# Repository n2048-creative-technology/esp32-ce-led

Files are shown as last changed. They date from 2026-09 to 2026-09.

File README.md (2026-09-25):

# ESP32-C6 LED Controller Board

A compact 2-layer PCB built around the **ESP32-C6-WROOM-1** module, providing
USB-C power/programming, on-board 3.3V regulation, ESD-protected USB
data lines, a reset button, and an addressable/status LED header. All
electronic parts are sourced against JLCPCB's live parts catalog for
turnkey assembly.

## 3D Renders

| Top side (regulator / passives) | Bottom side (ESP32 module / USB-C) |
|---|---|
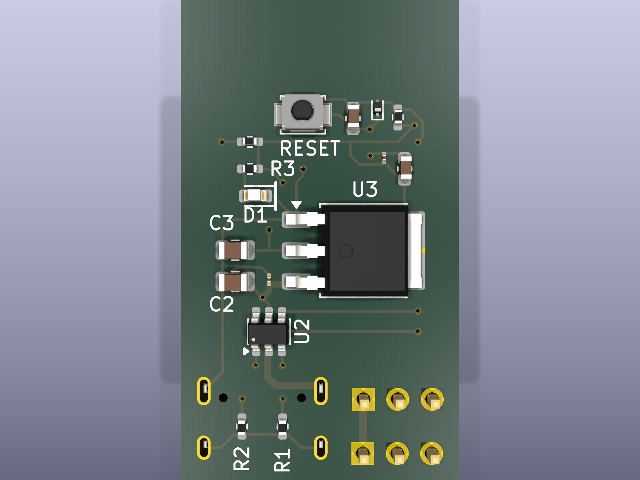
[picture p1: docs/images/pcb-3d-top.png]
PCB top 3D render
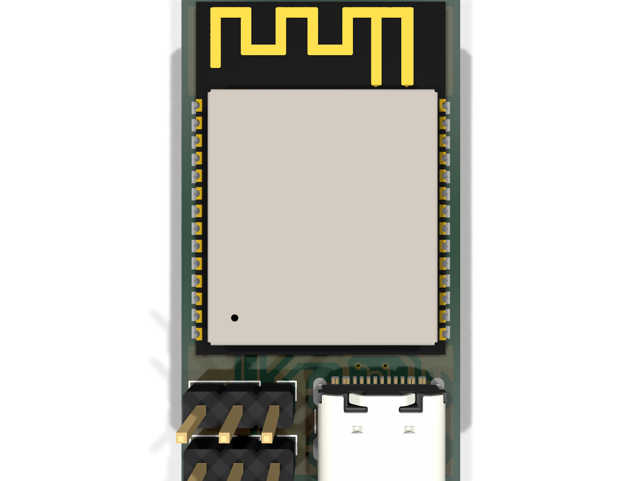
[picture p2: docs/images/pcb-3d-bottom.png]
PCB bottom 3D render
|  |  |

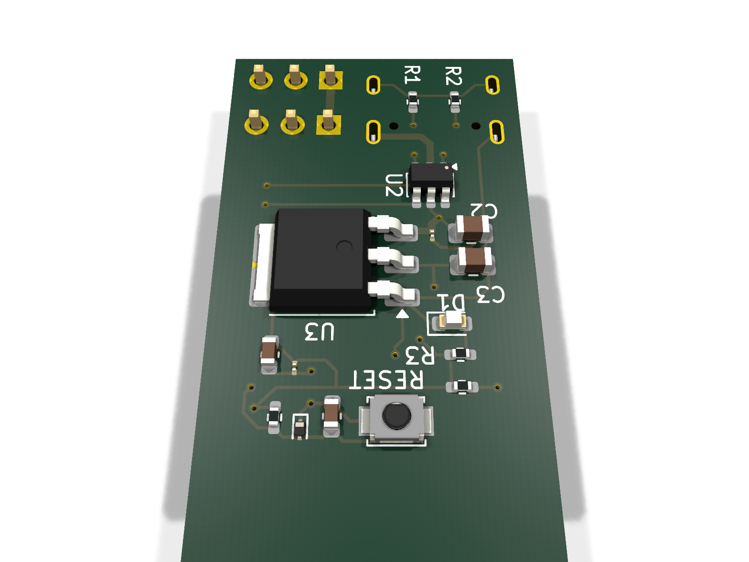
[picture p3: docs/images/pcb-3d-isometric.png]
PCB isometric 3D render


## Schematic

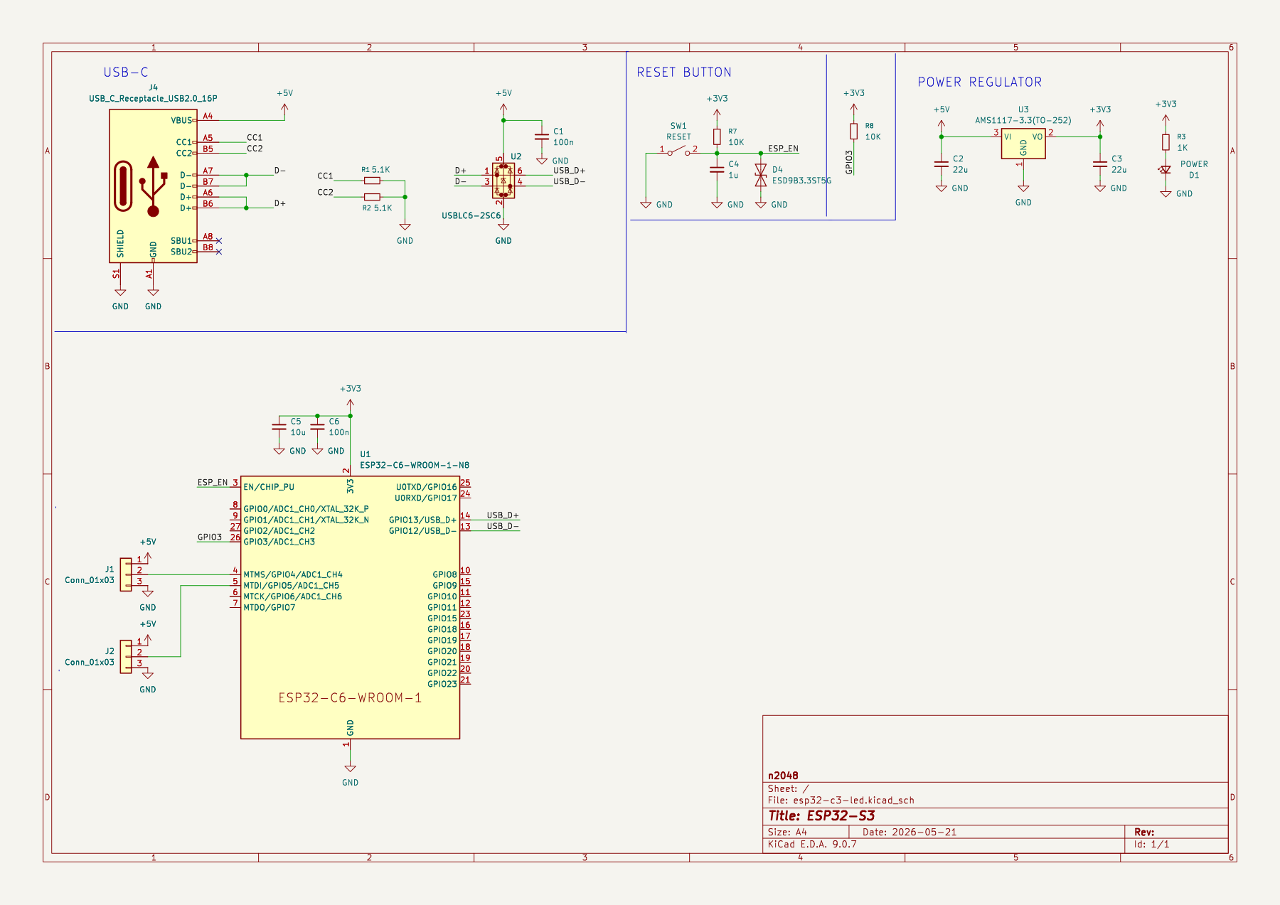
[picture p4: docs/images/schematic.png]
Schematic


Full-resolution vector version: [`docs/images/schematic.pdf`](docs/images/schematic.pdf)

## PCB Layout

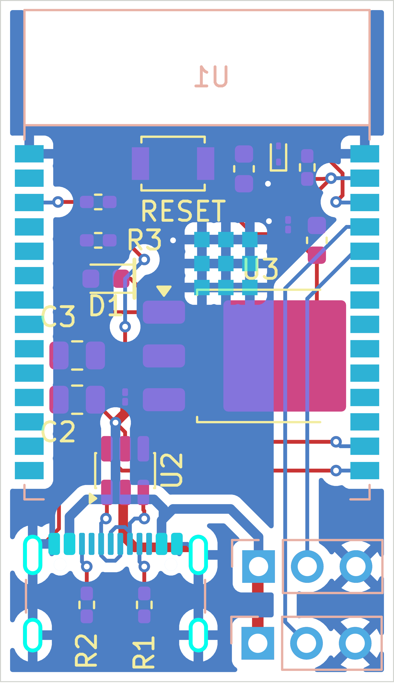
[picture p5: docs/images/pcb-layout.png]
PCB layout


*Copper (F.Cu / B.Cu), silkscreen, and solder mask layers, board outline shown.*

## Board Specs

- **Size:** 20.55 mm × 35.55 mm
- **Layers:** 2 (F.Cu / B.Cu)
- **MCU:** ESP32-C6-WROOM-1-N8 (Wi-Fi 6, Bluetooth 5 LE, Zigbee/Thread 802.15.4, 8 MB flash)
- **Power in:** USB-C (5V), on-board AMS1117-3.3 LDO regulator for 3.3V rail
- **USB protection:** USBLC6-2SC6-FS ESD protection on D+/D-
- **User I/O:** Reset button (SW1), status LED (D1), 2× 3-pin headers (J1/J2) for external LED/peripheral connections
- **ESD protection:** ESD9B3.3ST5G on EN line

## Bill of Materials

All parts verified against the live JLCPCB Open Platform API (real-time stock/pricing).
Full machine-readable BOM: [`BOM_jlcpcb_verified.csv`](BOM_jlcpcb_verified.csv)

| Ref | Part | LCSC # | Library |
|---|---|---|---|
| U1 | ESP32-C6-WROOM-1-N8 | C5366877 | Extended |
| U2 | USBLC6-2SC6-FS | C6807798 | Extended |
| U3 | AMS1117-3.3(TO-252) | C41347676 | Extended |
| D1 | KT-0603R (red LED) | C2286 | **Basic** |
| D4 | ESD9B3.3ST5G | C96512 | Extended |
| SW1 | B3U-1000P (tactile switch) | C231329 | Extended |
| J1, J2 | HX PH254-01-03-Z-L11.5 (1×3 header) | C52016391 | Extended |
| J4 | USB4105-GF-A (USB-C receptacle, 16P) | C3020560 | Extended |
| R1, R2 | 5.1kΩ 0402 | C25905 | **Basic** |
| R3 | 1kΩ 0402 | C11702 | **Basic** |
| R7, R8 | 10kΩ 0402 | C25744 | **Basic** |
| C1, C6 | 100nF 01005 | C307376 | Extended |
| C2, C3 | 22µF 0805 | C129302 | Extended |
| C4 | 1µF 0603 | C15849 | **Basic** |
| C5 | 10µF 0603 | C7472959 | Extended |

## Manufacturing

Board is set up for JLCPCB fabrication + assembly out of the box.
`production/` contains regenerated, verified fabrication files:

- `esp32-c3-led_gerbers.zip` — Gerbers + Excellon drill file (upload
  directly to JLCPCB's PCB order)
- `bom.csv` — JLCPCB-format BOM with a populated `LCSC Part #` column
  for every line (Comment / Designator / Footprint / LCSC Part #);
  each part number is a live, in-stock JLCPCB catalog match
- `positions.csv` — CPL / pick-and-place file (Ref, Val, Package,
  PosX, PosY, Rot, Side), regenerated from the current board so
  bottom-side parts (J1, J2, J4, U1) are correctly marked `bottom`

`esp32-c3-led.kicad_pro` / `.kicad_sch` / `.kicad_pcb` remain the
authoritative KiCad 9 source files; every part also carries `LCSC` and
`MPN` custom fields on its schematic symbol.

> **Note:** an earlier BOM/CPL pair generated by the Fabrication
> Toolkit KiCad plugin shipped with an empty `LCSC Part #` column,
> which caused JLCPCB's auto-matcher to select wrong/out-of-stock
> substitutes and fail to match the connectors (J1/J2/J4) entirely.
> The files above were regenerated directly from the schematic's
> verified LCSC data and confirmed against the live JLCPCB API —
> use these instead of re-running the plugin unless the design changes.

### Design Rule Check status

Verified clean via `kicad-cli pcb drc`: only 3 benign warnings remain
(`lib_footprint_mismatch` on C1/C6/D1, confirming intentional local
customizations — see below). No copper clearance errors, no
dangling/floating silkscreen text, no component placement changes.

### Assembly orientation / silkscreen clarity

To avoid JLCPCB assembly clarification requests, every part with a
genuine orientation dependency has an unambiguous silkscreen or
Gerber-encoded marker:

- **D1 (LED, polarized)** — cathode (pin 1) marked with a bold bar on
  the silkscreen outline, matching its datasheet K/A pinout.
- **SW1, U2** — tactile switch and ESD IC footprints already carry a
  pin-1 triangle marker from their library footprints.
- **J1, J2 (headers)** — pin 1 uses a square pad vs. round pads on 2/3,
  the standard machine-readable convention (read directly from the
  Gerbers/CPL, not silkscreen).
- **J4 (USB-C receptacle), U3 (TO-252 regulator)** — mechanically keyed
  / self-orienting packages; cannot be placed backwards.
- **D4 (ESD9B3.3ST5G)** — confirmed **bidirectional** TVS diode per
  datasheet; orientation is electrically irrelevant, so intentionally
  left unmarked.
- **U1 (ESP32-C6-WROOM-1)** — uses Espressif's official reference
  footprint; JLCPCB sources rotation from the CPL file, not visual
  silkscreen inspection, for this standard module.

## Repo Layout

```
esp32-c3-led.kicad_pro      KiCad project
esp32-c3-led.kicad_sch      Schematic
esp32-c3-led.kicad_pcb      PCB layout
BOM_jlcpcb_verified.csv     Reference BOM with LCSC part numbers (grouped by value)
docs/images/                Renders and diagrams (this README)
production/                  JLCPCB-ready fabrication output:
  esp32-c3-led_gerbers.zip     Gerbers + drill (upload as-is)
  bom.csv                      JLCPCB BOM (Comment/Designator/Footprint/LCSC Part #)
  positions.csv                CPL / pick-and-place file
  gerbers/                     Individual Gerber/drill layer files
```

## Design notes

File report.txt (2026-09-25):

Front (top side) placement file: '/home/mauricio/n2048/silvia/esp32-s3/esp32-s3-top.pos'.
Info: Component count: 36.
Back (bottom side) placement file: '/home/mauricio/n2048/silvia/esp32-s3/esp32-s3-bottom.pos'.
Info: Component count: 0.
Info: Full component count: 36.
Info: Done.
Front (top side) placement file: '/home/mauricio/n2048/silvia/esp32-s3/esp32-s3-top.pos'.
Info: Component count: 36.
Back (bottom side) placement file: '/home/mauricio/n2048/silvia/esp32-s3/esp32-s3-bottom.pos'.
Info: Component count: 0.
Info: Full component count: 36.
Info: Done.

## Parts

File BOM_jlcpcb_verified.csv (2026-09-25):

reference | value | footprint | layer
U3 | LM1117DT-3.3 | Package_TO_SOT_SMD:TO-252-3_TabPin2 | F.Cu
C5 | 10u | Capacitor_SMD:C_0603_1608Metric | F.Cu
D4 | ESD3.3 | Diode_SMD:D_SOD-923 | F.Cu
C2 | 22u | Capacitor_SMD:C_0805_2012Metric | F.Cu
C1 | 100n | Capacitor_SMD:C_01005_0402Metric_Pad0.57x0.30mm_HandSolder | F.Cu
C4 | 1u | Capacitor_SMD:C_0603_1608Metric | F.Cu
D1 | POWER | LED_SMD:LED_0603_1608Metric | F.Cu
U2 | USBLC6-2SC6 | Package_TO_SOT_SMD:SOT-23-6 | F.Cu
R7 | 10K | Resistor_SMD:R_0402_1005Metric_Pad0.72x0.64mm_HandSolder | F.Cu
SW1 | RESET | Button_Switch_SMD:SW_SPST_B3U-1000P | F.Cu
R2 | 5.1K | Resistor_SMD:R_0402_1005Metric_Pad0.72x0.64mm_HandSolder | F.Cu
R1 | 5.1K | Resistor_SMD:R_0402_1005Metric_Pad0.72x0.64mm_HandSolder | F.Cu
C6 | 100n | Capacitor_SMD:C_01005_0402Metric_Pad0.57x0.30mm_HandSolder | F.Cu
R3 | 1K | Resistor_SMD:R_0402_1005Metric_Pad0.72x0.64mm_HandSolder | F.Cu
R8 | 10K | Resistor_SMD:R_0402_1005Metric_Pad0.72x0.64mm_HandSolder | F.Cu
C3 | 22u | Capacitor_SMD:C_0805_2012Metric | F.Cu
J1 | Conn_01x03 | Connector_PinHeader_2.54mm:PinHeader_1x03_P2.54mm_Vertical | B.Cu
J4 | USB_C_Receptacle_USB2.0_16P | Connector_USB:USB_C_Receptacle_GCT_USB4105-xx-A_16P_TopMnt_Horizontal | B.Cu
U1 | ESP32-C6-WROOM-1 | PCM_Espressif:ESP32-C6-WROOM-1 | B.Cu
J2 | Conn_01x03 | Connector_PinHeader_2.54mm:PinHeader_1x03_P2.54mm_Vertical | B.Cu

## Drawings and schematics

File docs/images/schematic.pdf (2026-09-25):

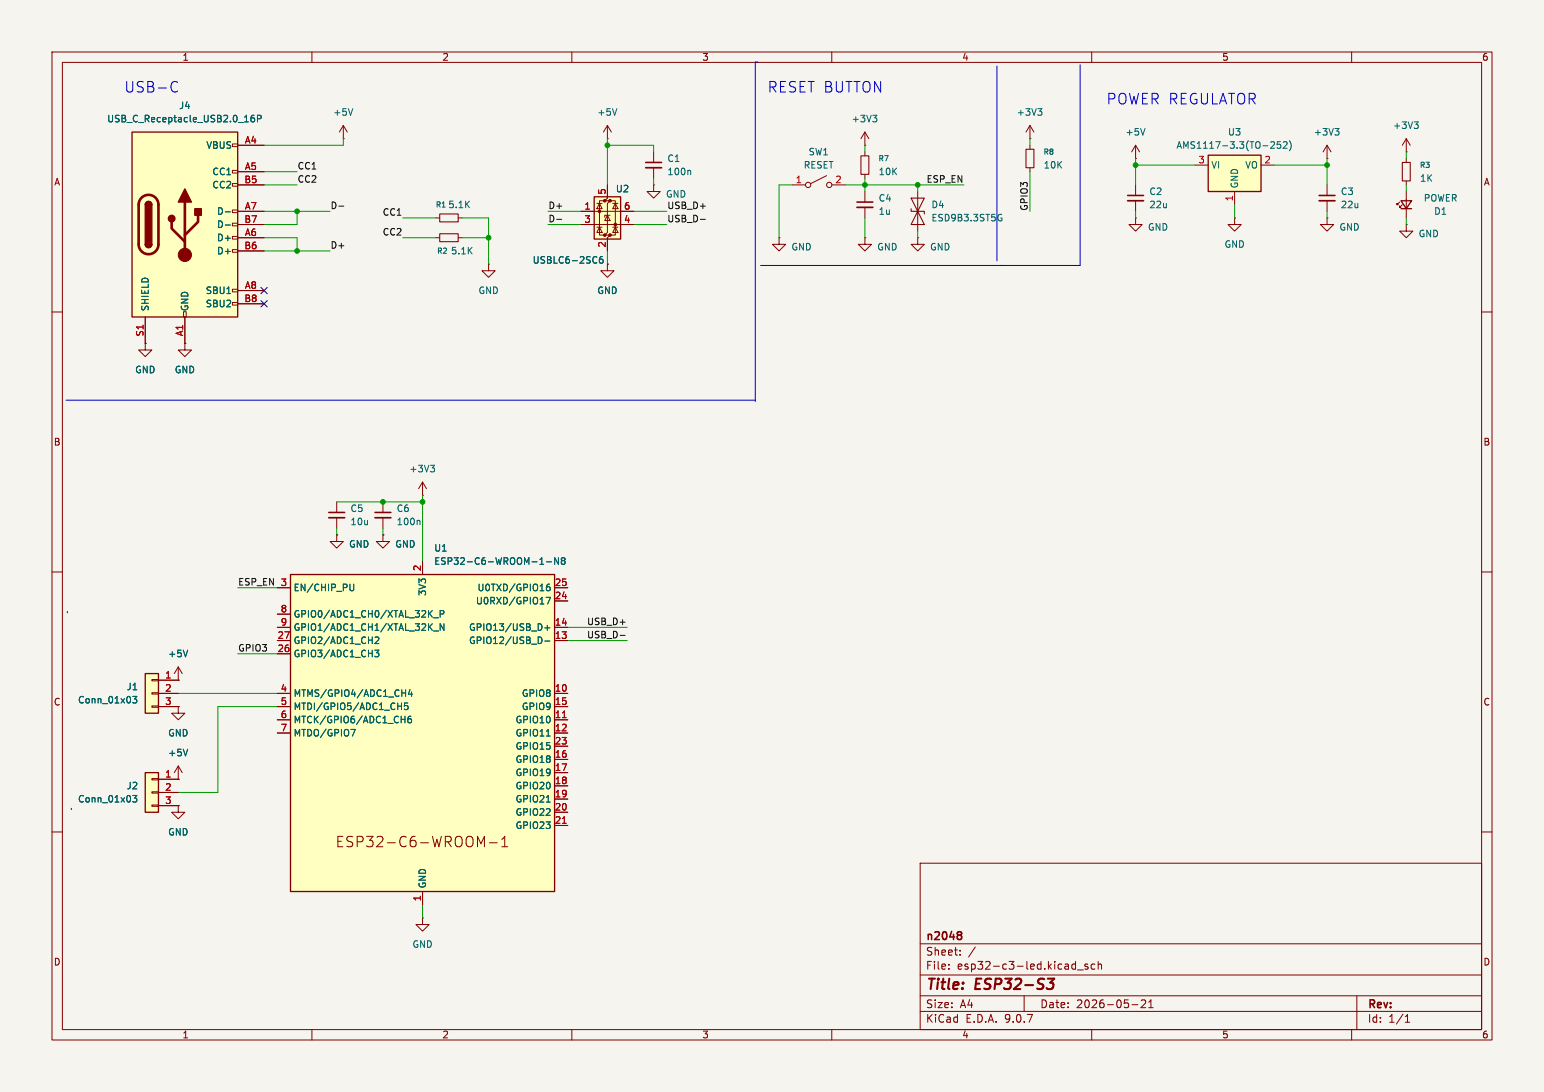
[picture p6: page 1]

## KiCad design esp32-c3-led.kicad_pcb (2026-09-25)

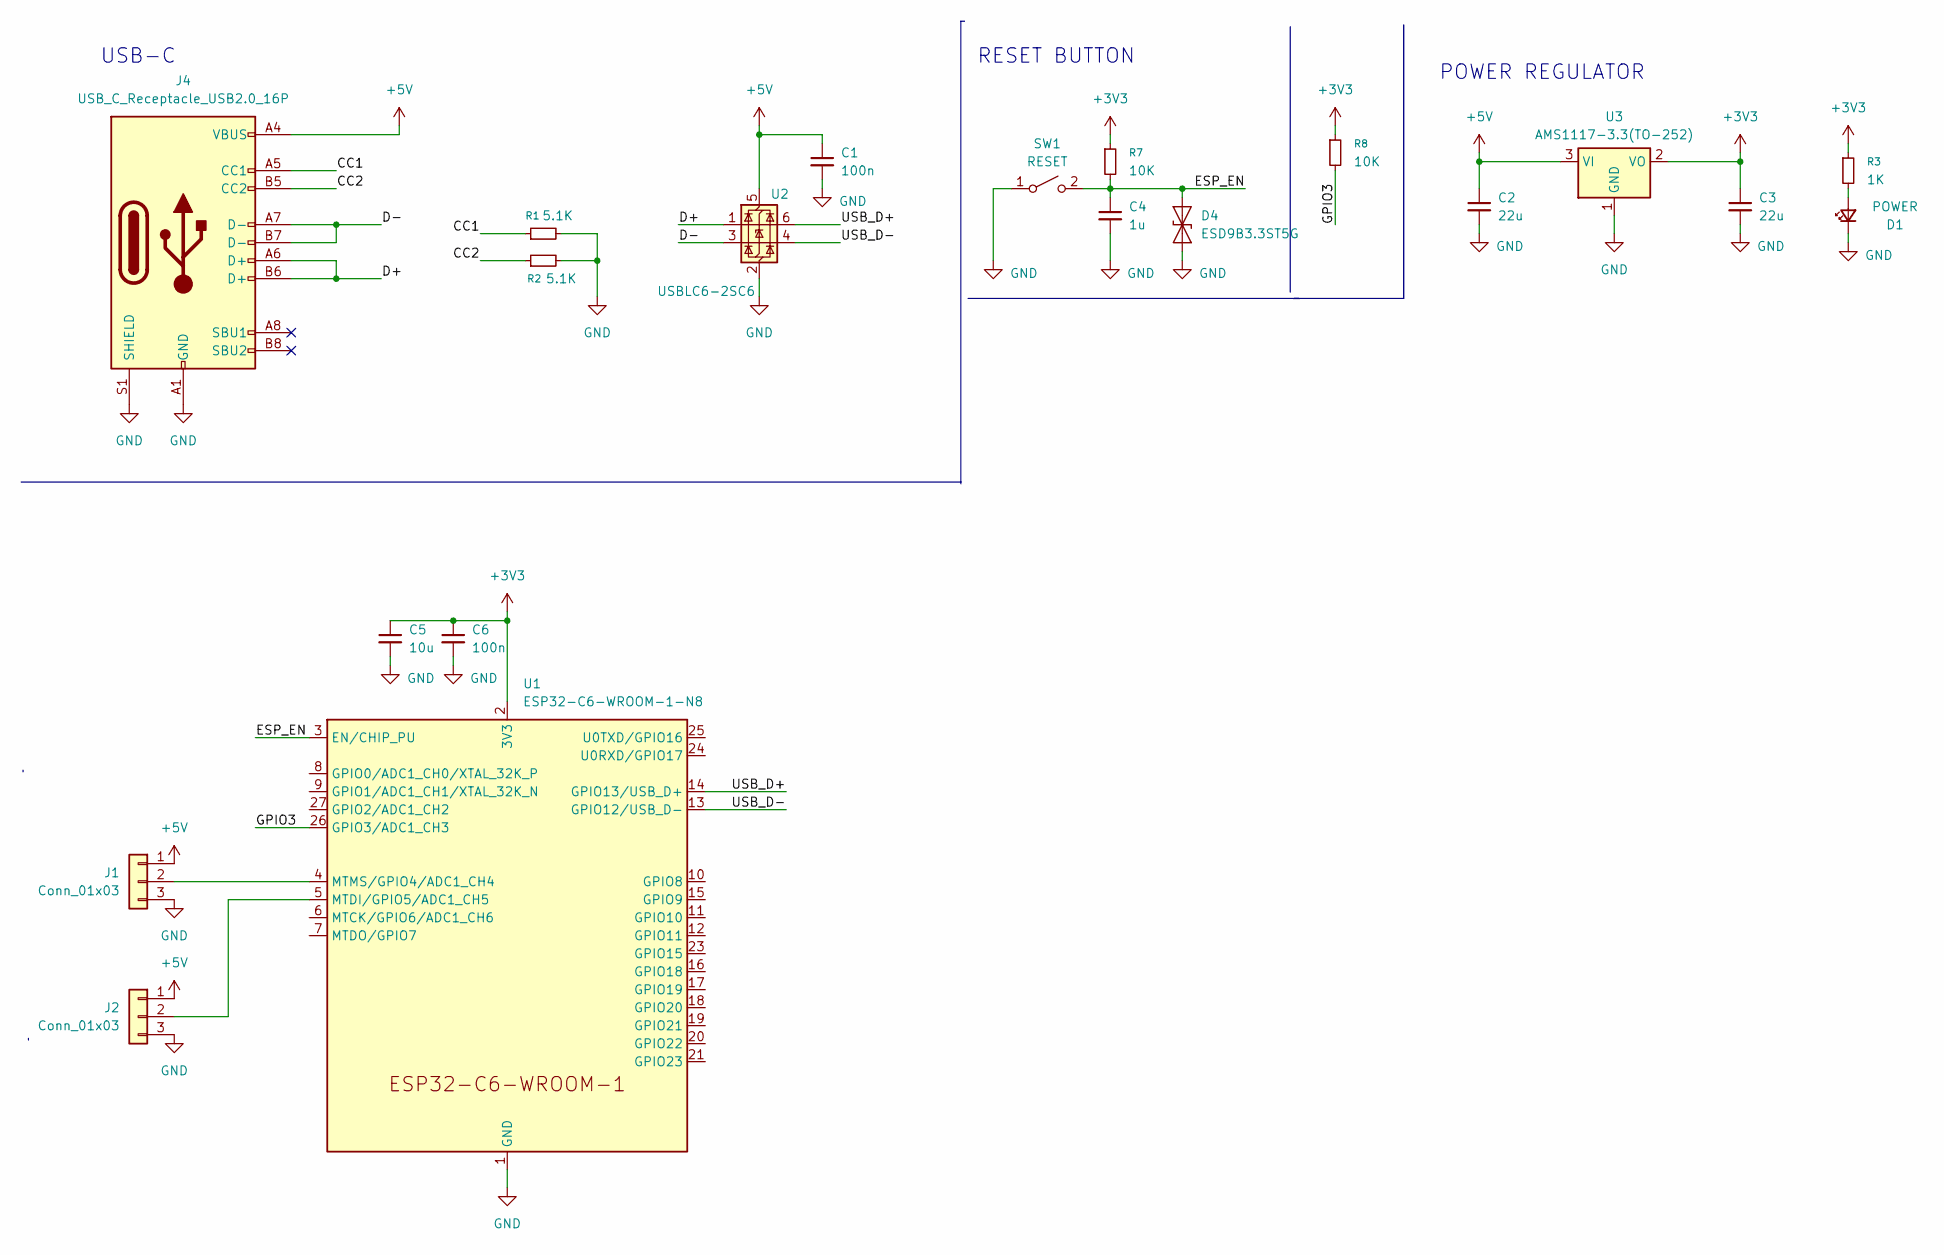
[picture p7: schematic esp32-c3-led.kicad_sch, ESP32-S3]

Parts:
C1, C6: 100n; C_01005_0402Metric; MPN CL02A104MQ2NNNC; LCSC C307376
C2, C3: 22u; C_0805_2012Metric; MPN 0805X226M160NT; LCSC C129302
C4: 1u; C_0603_1608Metric; MPN CL10A105KB8NNNC; LCSC C15849
C5: 10u; C_0603_1608Metric; MPN HGC0603R5106M160NTHJ; LCSC C7472959
D1: POWER; LED_0603_1608Metric; MPN KT-0603R; LCSC C2286
D4: ESD9B3.3ST5G; D_SOD-923; MPN ESD9B3.3ST5G; LCSC C96512
J1, J2: Conn_01x03; PinHeader_1x03_P2.54mm_Vertical; MPN HX PH254-01-03-Z-L11.5; LCSC C52016391
J4: USB_C_Receptacle_USB2.0_16P; USB_C_Receptacle_GCT_USB4105-xx-A_16P_TopMnt_Horizontal; MPN USB4105-GF-A; LCSC C3020560
R1, R2: 5.1K; R_0402_1005Metric_Pad0.72x0.64mm_HandSolder; MPN 0402WGF5101TCE; LCSC C25905
R3: 1K; R_0402_1005Metric_Pad0.72x0.64mm_HandSolder; MPN 0402WGF1001TCE; LCSC C11702
R7, R8: 10K; R_0402_1005Metric_Pad0.72x0.64mm_HandSolder; MPN 0402WGF1002TCE; LCSC C25744
SW1: RESET; SW_SPST_B3U-1000P; MPN B3U-1000P; LCSC C231329
U1: ESP32-C6-WROOM-1-N8; ESP32-C6-WROOM-1; MPN ESP32-C6-WROOM-1-N8; LCSC C5366877
U2: USBLC6-2SC6; SOT-23-6; MPN USBLC6-2SC6-FS; LCSC C6807798
U3: AMS1117-3.3(TO-252); TO-252-3_TabPin2; MPN AMS1117-3.3(TO-252); LCSC C41347676

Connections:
+3V3: C3.1, C5.1, C6.1, R3.1, R7.1, R8.1, U1.2 (3V3), U3.2 (VO)
+5V: C1.1, C2.1, J1.1, J2.1, J4.A4 (VBUS), J4.A9 (VBUS), J4.B4 (VBUS), J4.B9 (VBUS), U2.5 (VBUS), U3.3 (VI)
CC1: J4.A5 (CC1), R1.1
CC2: J4.B5 (CC2), R2.1
D+: J4.A6 (D+), J4.B6 (D+), U2.1 (I/O1)
D-: J4.A7 (D-), J4.B7 (D-), U2.3 (I/O2)
ESP_EN: C4.1, D4.2 (A2), R7.2, SW1.2 (B), U1.3 (EN/CHIP_PU)
GND: C1.2, C2.2, C3.2, C4.2, C5.2, C6.2, D1.1 (K), D4.1 (A1), J1.3, J2.3, J4.A1 (GND), J4.A12 (GND), J4.B1 (GND), J4.B12 (GND), J4.S1 (SHIELD), R1.2, R2.2, SW1.1 (A), U1.1 (GND), U1.28 (GND), U1.29 (GND), U2.2 (GND), U3.1 (GND)
GPIO3: R8.2, U1.26 (GPIO3/ADC1_CH3)
unnamed: D1.2 (A), R3.2
unnamed: J1.2, U1.4 (MTMS/GPIO4/ADC1_CH4)
unnamed: J2.2, U1.5 (MTDI/GPIO5/ADC1_CH5)
USB_D+: U1.14 (GPIO13/USB_D+), U2.6 (I/O1)
USB_D-: U1.13 (GPIO12/USB_D-), U2.4 (I/O2)

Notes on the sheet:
RESET BUTTON
USB-C
POWER REGULATOR

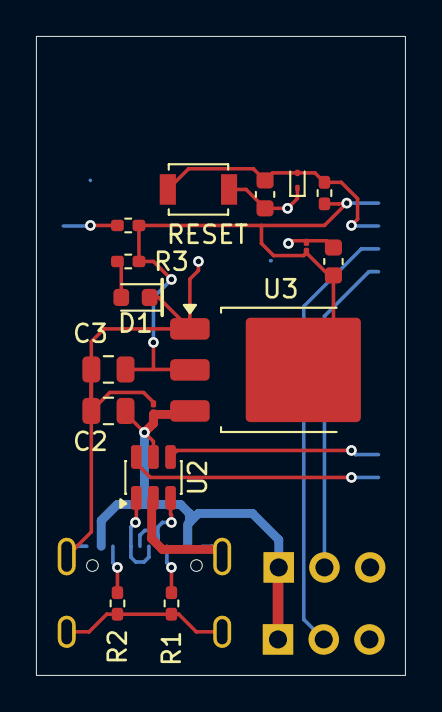
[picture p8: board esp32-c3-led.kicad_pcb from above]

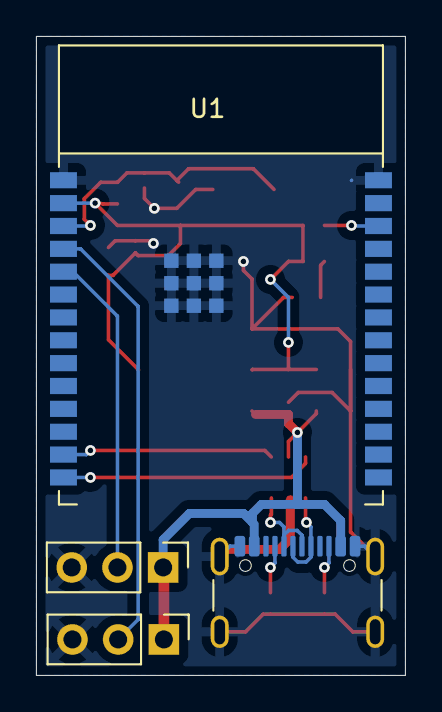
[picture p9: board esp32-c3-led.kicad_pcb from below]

Board: 2 copper layers, 20.5 x 35.5 mm, 20 parts (4 on the bottom side), 14 nets.

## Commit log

2026-09-25 kicad project
    [bom.csv, designators.csv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]
2026-09-25 Re-source all BOM parts to live JLCPCB-stocked components
    Re-selected every sourced part against the live JLCPCB Open Platform API
    (real-time stock/pricing) to replace discontinued or zero-stock parts:
    - U1 ESP32-C6-WROOM-1 -> ESP32-C6-WROOM-1-N8 (C5366877)
    - U2 USBLC6-2SC6 -> USBLC6-2SC6-FS (C6807798)
    - U3 LM1117DT-3.3 (no stock) -> AMS1117-3.3(TO-252) (C41347676)
    - D1 generic LED -> KT-0603R red LED, Basic part (C2286)
    - D4 ESD3.3 (no stock) -> ESD9B3.3ST5G (C96512)
    - SW1 RESET switch -> B3U-1000P (C231329)
    - J1/J2 pin headers -> HX PH254-01-03-Z-L11.5 (C52016391)
    - J4 USB-C receptacle (dead variant) -> USB4105-GF-A (C3020560)
    - R1/R2 5.1K, R3 1K, R7/R8 10K -> JLCPCB Basic-library 0402 re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
    [BOM_jlcpcb_verified.csv, esp32-c3-led.kicad_pcb, esp32-c3-led.kicad_sch]
2026-09-25 Add README with board docs, schematic, PCB layout, and 3D renders
    - README.md: board overview, specs, BOM table (LCSC-sourced), repo layout
    - docs/images/: 3D renders (top, bottom, isometric), schematic PNG/PDF,
    and PCB layout PNG generated via kicad-cli
    - Images generated from the current (JLCPCB-verified) schematic/PCB
    state; no design changes made
2026-09-25 Fix mirrored RESET silkscreen text on SW1
    SW1's 'RESET' value label on F.SilkS had a stray (justify mirror)
    directive, causing it to render backwards when viewed from the top
    of the board. Removed the mirror flag -- text now reads correctly.
    This was the only mirrored text on the front silkscreen; the mirror
    flags on U1/J1/J2/J4 labels are correct as-is since those footprints
    sit on the back copper layer and are properly mirrored so their text
    reads correctly when the board is viewed from the bottom.
    No footprints, pads, nets, or placements changed. DRC violation count
    dropped 17 -> 16 (one silk-related check cleared), all other
    violations unchanged and pre-existing in the original design.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
    [esp32-c3-led.kicad_pcb]
2026-09-25 Fix DRC clearance and silkscreen violations
    - C1/C6 (01005 100nF caps): switched from the HandSolder footprint
    variant (oversized 0.575x0.3mm pads) to the standard
    C_01005_0402Metric footprint, with a local 0.05mm pad clearance
    override to satisfy the board's 0.2mm netclass rule against the
    01005 package's inherent 0.1mm pad-to-pad gap. Same position,
    rotation, and net assignments -- only pad geometry corrected to
    spec (also matches what JLCPCB machine assembly expects; hand-solder
    pads serve no purpose on a PCBA order).
    - Hid redundant/overlapping Reference silkscreen labels on C1, C5, C6,
    R8, J1, J2, J4 that were clipped by solder mask or overlapping
    neighboring text. Va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
    [esp32-c3-led.kicad_pcb, esp32-c3-led.kicad_sch]
2026-09-25 Update documentation and renders after DRC fixes
    - README: note the DRC-clean status and rationale for the remaining
    benign lib_footprint_mismatch warnings
    - Regenerated 3D renders (top/bottom/isometric) and PCB layout PNG
    from the current board state (post C1/C6 footprint fix and hidden
    silkscreen reference labels)
    - schematic.png/pdf unchanged (no schematic-visible content changed
    by the DRC fixes)
2026-09-25 Regenerate JLCPCB fabrication files with correct LCSC part numbers
    The Fabrication Toolkit plugin's previous BOM (production/bom.csv) had
    a completely empty LCSC Part # column, causing JLCPCB's BOM/CPL
    uploader to auto-match wrong/out-of-stock substitutes and fail to
    match the connectors (J1, J2, J4) entirely -- 2 parts unselected, 1
    inventory shortage, as seen in the upload preview.
    Regenerated from scratch using the schematic's verified LCSC data
    (set during the earlier JLCPCB re-sourcing pass) and kicad-cli:
    - production/bom.csv: JLCPCB-format BOM (Comment/Designator/Footprint/
    LCSC Part #) with all 15 unique line items populated. Every LCSC
    number re-verified live against the JLCPC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
    [bom.csv, designators.csv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]
2026-09-25 Add cathode orientation marker to D1 to avoid JLCPCB assembly queries
    Audited every part on the board for orientation ambiguity (the class
    of issue that triggers JLCPCB's pre-assembly clarification emails):
    - D1 (LED, polarized, pin 1 = cathode per Sim.Pins "1=K 2=A") had a
    plain thin-outline footprint with no visible polarity marker.
    Added a bold 0.2mm silkscreen bar on the cathode (pin 1) side,
    matching the physical part's pad position after its 180 deg
    placement rotation.
    - Confirmed D4 (ESD9B3.3ST5G) is a BIDIRECTIONAL TVS diode per its
    onsemi datasheet -- orientation is electrically irrelevant, so it is
    intentionally left unmarked (a marker there would be misleading).
    - Con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
    [esp32-c3-led-B_Cu.gbl, esp32-c3-led-B_Mask.gbs, esp32-c3-led-B_Paste.gbp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]
